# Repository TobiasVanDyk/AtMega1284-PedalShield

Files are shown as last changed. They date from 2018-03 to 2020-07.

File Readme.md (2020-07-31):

# The ATMega1284P Guitar and Music Effects Pedal 

Instructable at: https://www.instructables.com/id/ATMega1284P-Guitar-and-Music-Effects-Pedal/

I have ported the Arduino Uno ATMega328 Pedalshield (as developed by Electrosmash and in part based on work at the Open Music Lab) to the ATMega1284P which has eight times more RAM than the Uno (16kB versus 2kB). An additional unexpected benefit is that the Mega1284 build has much lower noise component - to the extent that when I compare the Uno and the Mega1284 using the same support circuitry it is not unreasonable to describe the Uno as "noisy" and the Mega1284 as "quiet". The larger RAM means that a much longer delay effect can be obtained - and that is demonstrated by the Arduino sketch example that I have included. The background breathing noise when using the Tremelo effect is also (almost) absent with the ATMega1284. 

A comparison of three Atmel AVR microprocessors namely the 328P that is the Uno, the 2560P that is the Mega2560, and the Mega1284 shows the latter to have the most RAM of the three: 

|Aspect | 328P | 1284P  | 2560P |
|---|---|---|---|
|RAM 	 |	2k 	 | 16k | 8k |
|Flash 	 |	32k  | 128k | 256k  |
|EEPROM |	1k	 | 4k 	  | 4k |
|UART 	 |	1 	 | 2 	 | 4 |
|IO Pins |	23 	 | 32 	  | 86 |
|Interrupts |	2 	 | 3 | 8 |
|Analog Inputs| 6	 | 8 	 | 16 |

I started by bread-boarding the Uno-based pedalSHIELD as in the Electrosmash specification but I did not have the same RRO OpAmp as specified. As a result I ended up with a circuit which I considered to give acceptable results. The details of this Uno version are given in appendix 2. This same circuit was then ported to the ATMega1284 - surprisingly apart from the non-essential changes such as assigning the switches and LED to a different port, and allocating 12,000 kB instead of 2,000 kB of RAM for the delay buffer, only **one essential change had to be made in the source code, namely changing the Timer1/PWM OC1A and OC1B outputs from Port B on the Uno to Port D (PD5 and PD4) on the ATMega1284.** 

I later discovered the excellent modifications to the electrosmash circuit by Paul Gallagher and after testing, this is the circuit I will present here - but then also with the substitution of the Uno with the Mega1284 and using a Texas Instruments TLC2272 as the OpAmp, and because of the excellent noise performance of the Mega1284 I could also raise the low-pass filter frequency level. It is important to note that although development boards for the ATMega1284 are available (Github: MCUdude MightyCore), it is an easy exercise to buy the bare (bootloader-free) chip (buy the PDIP version which is bread-board and strip-board friendly), then load the Mark Pendrith fork of the Maniacbug Mighty-1284p Core Optiboot bootloader or the MCUdude Mightycore, by using an Uno as the ISP programmer, and then loading sketches again via the Uno to the AtMega1284. Details and links for this process are given in appendix 1. 

I would like to acknowledge the three most important sources from which further information can be obtained and will give links to their websites and the end of this article: Electrosmash, Openlabs Music, and Tardate/Paul Gallagher Construction and Parts list: 

### Parts list: 

* ATMega1284P (PDIP 40 pin package version) Arduino Uno R3 (used as an ISP to transfer the bootloader and sketches to the ATMega1284) 
* OpAmp TLC2272 (or similar RRIO (Rail to Rail Input and Output) OpAmp such as MCP6002, LMC6482, TL972) 
* Red LED 16 MHz crystal 
* 2 x 27 pF capacitors 
* 5 x 6n8 capacitors 
* 270 pF capacitor 
* 4 x 100n capacitors 
* 2 x 10uF 16v electrolytic capacitors 
* 6 x 4k7 resistors 
* 100k resistor 
* 2 x 1M resistors 
* 470 ohm resistor 
* 1M2 resistor 
* 100k Potentiometer 
* 3 x pushbutton switches (one of them should be substituted with a 3-pole 2-way footswitch if the effects box is going to be used for live work) 

### Construction:

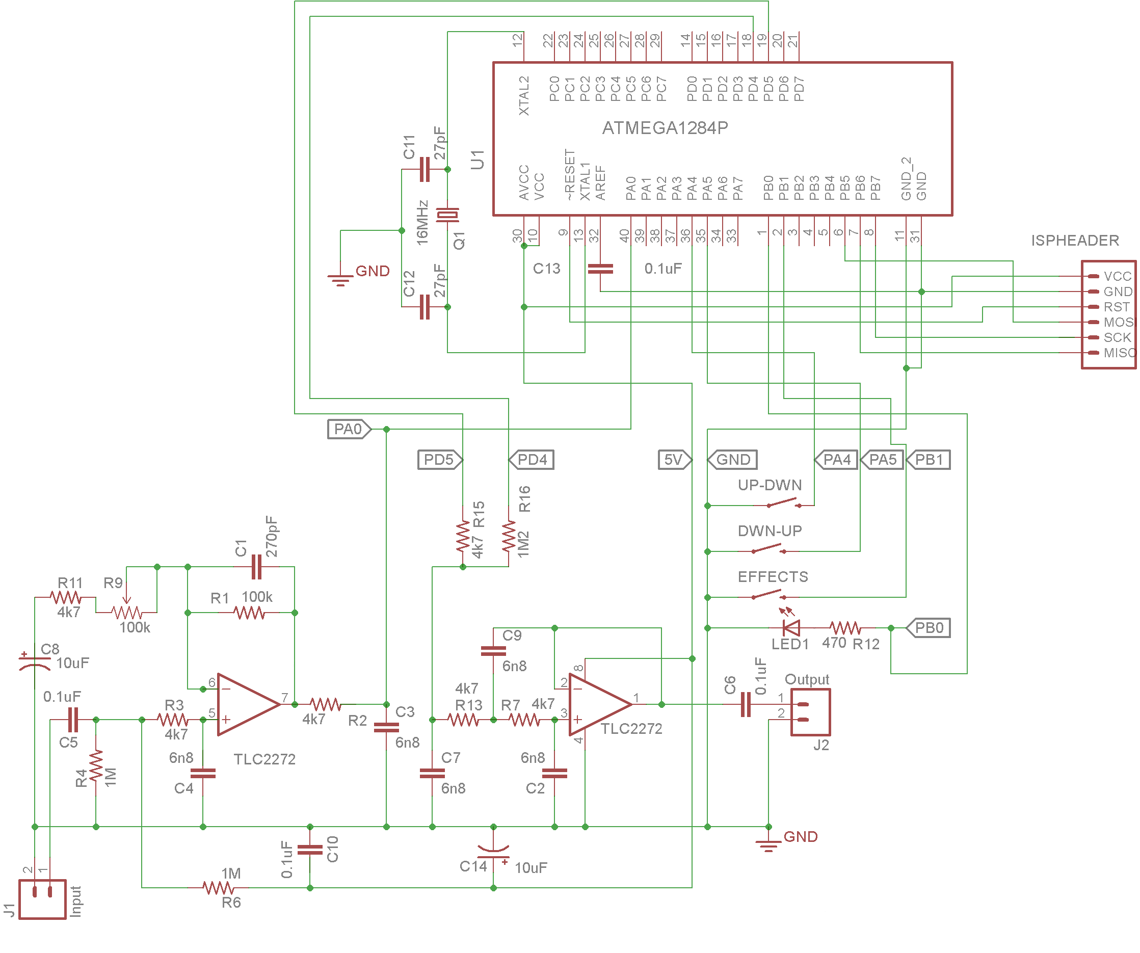
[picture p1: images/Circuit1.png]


Schematic 1 gives the circuit used and Breadboard 1 is its physical representation (Fritzing 1) with Photo 1 the actual bread-boarded circuit in operation. It may be advantageous to have a potentiometer as a mixer for the dry (equal to the input) and the wet (after processing by the MCU) signal, and Schematic 2, Breadboard 2 and Photo 2 gives the circuit details of a previously constructed circuit which incorporates such an input to output mixer. Also look at the Open Music Labs StompBox for another mixer implementation using four OpAmps. 

**OpAmp Input and Output Stages:** It is important that a RRO or preferably a RRIO OpAmp is used because of the large voltage swing required at the OpAmp output to the ADC of the ATMega1284. The parts list contains a number of alternative OpAmp types. The 100k potentiometer is used to adjust the input gain to a level just below any distortion, and it can also be used to adjust the input sensitivity for an input source other than a guitar such as a music player. The OpAmp output stage has a higher order RC filter to remove the digitally generated MCU noise from the audio stream. 

**ADC Stage:** The ADC is configured to be reading via an interrupt all the whole time. Note that a 100nF capacitor should be connected between the AREF pin of the ATMega1284 and ground to reduce noise as an internal Vcc source is used as a reference voltage - do NOT connect the AREF pin to +5 volt directly! 

**DAC PWM Stage:** As the ATMega1284 does not have its own DAC, the output audio waveforms are generated using a pulse width modulation of an RC filter. The two PWM outputs on PD4 and PD5 are set as the high and low bytes of the audio output and mixed with the two resistors (4k7 and 1M2) in a 1:256 ratio (low byte and high byte) - which generates the audio output. It may be worthwhile experimenting with other resistor pairs such as the 3k9 1M ohm pair used by Open Music Labs in their StompBox. 

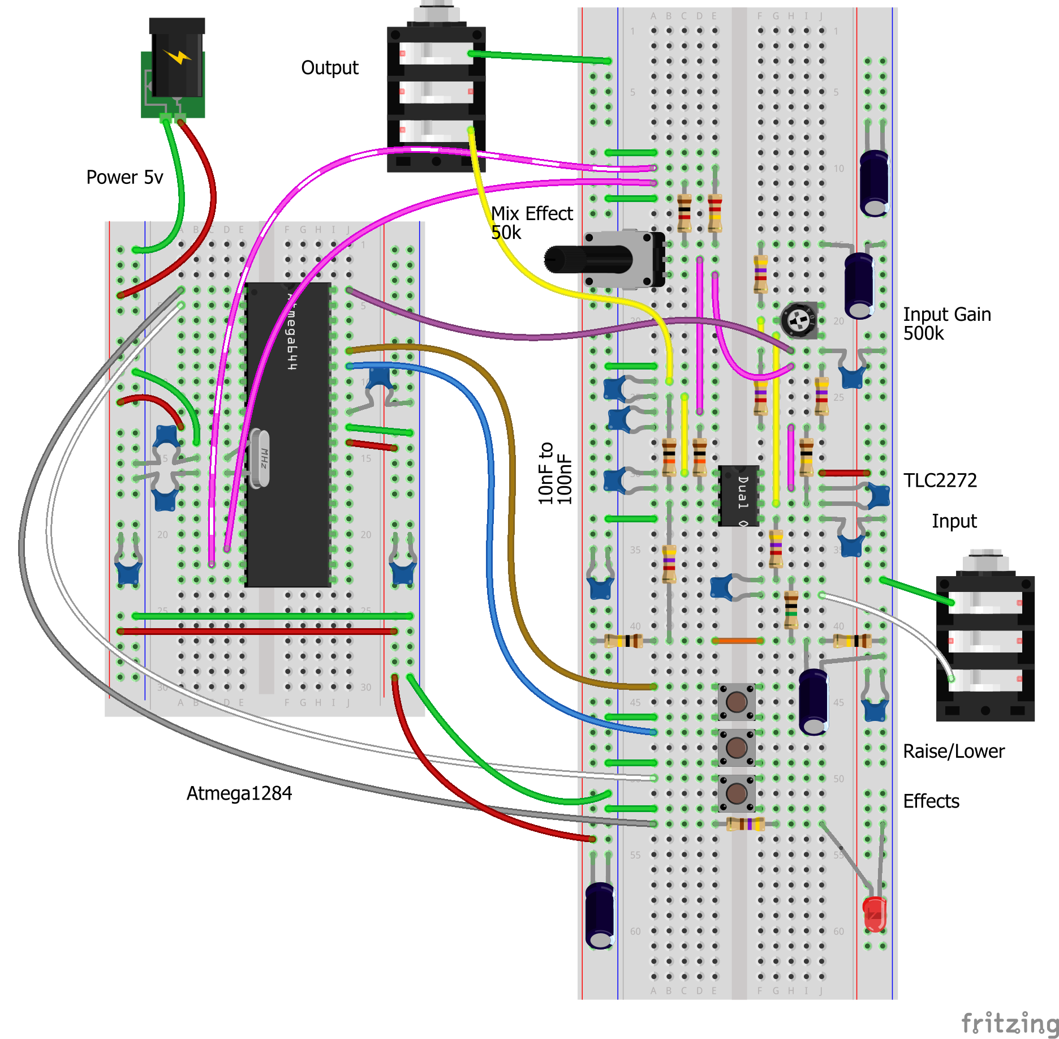
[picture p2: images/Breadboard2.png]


### Software: 

The software is based on the electrosmash sketches, and the example included (pedalshield1284delay.ino), has been adapted from their Uno delay sketch. Some of the switches and LED had been moved to other ports away from those used by the ISP programmer (SCLK, MISO, MOSI and Reset), the delay buffer has been increased from 2000 bytes to 12000 bytes, and PortD has been set as the output for the two PWM signals. Even with the increase in the delay buffer the sketch still use only about 70% of the available 1284 RAM. 

Other examples such as the octaver or tremolo from the electrosmash website for the pedalSHIELD Uno can be adapted for use by the Mega1284 by changing three sections in the code: 

(1) Change:
```
DDRB |= ((PWM_QTY << 1) | 0x02); 
to 
DDRD |= 0x30;
// The change above is the ONLY essential code change 
// when porting from the AtMega328 to the ATMega1284 
```

(2) Change:
``` 
#define LED 13 
#define FOOTSWITCH 12 
#define TOGGLE 2 
#define PUSHBUTTON_1 A5 
#define PUSHBUTTON_2 A4
to
#define LED PB0 
#define FOOTSWITCH PB1 
#define PUSHBUTTON_1 A5 
#define PUSHBUTTON_2 A4
```

(3) Change:
```
pinMode(FOOTSWITCH, INPUT_PULLUP); 
pinMode(TOGGLE, INPUT_PULLUP); 
pinMode(PUSHBUTTON_1, INPUT_PULLUP); 
pinMode(PUSHBUTTON_2, INPUT_PULLUP); 
pinMode(LED, OUTPUT)
to
pinMode(FOOTSWITCH, INPUT_PULLUP); 
pinMode(PUSHBUTTON_1, INPUT_PULLUP); 
pinMode(PUSHBUTTON_2, INPUT_PULLUP); 
pinMode(LED, OUTPUT);
```

The pushbuttons 1 and 2 are used in some of the sketches to increase or decrease an effect. In the delay example it increases or decreases the delay time. When the sketch is first loaded it starts with the maximum delay effect. press the down button - it takes about 20 seconds to count down all the way to the delay-off position - and then press and hold in the up button. Listen how the sweep effect of holding in the button changes the effect to that of a phaser, chorus and flanging, as well as the delay when the button is released.

To change the delay to an echo effect (add repetition) change the line:
```
DelayBuffer[DelayCounter] = ADC_high; 
to
DelayBuffer[DelayCounter] = (ADC_high + (DelayBuffer[DelayCounter]))>>1; 
```

The footswitch should be a three pole two way switch and must be connected as described on the electrosmash website. 

### Links: 
1. Electrosmash: https://www.electrosmash.com/pedalshield-uno 
License: https://creativecommons.org/licenses/by-nc/3.0/ 
2. Openlabs Music: http://wiki.openmusiclabs.com/wiki/StompShield License: http://www.openmusiclabs.com/ 
3. Paul Gallagher: https://github.com/tardate/LittleArduinoProjects/tree/master/playground/AudioDSP 
License: https://github.com/tardate/LittleArduinoProjects/blob/master/LICENSE (MIT) 
4. 1284 Bootloader: https://github.com/JChristensen/mighty-1284p https://github.com/maniacbug/mighty-1284p 
5. ATmega1284 8bit AVR Microcontroller: https://www.microchip.com/wwwproducts/en/ATmega1284 

### Appendix 1 

**Programming the ATMega1284P:** There are a few websites that gives a good explanation on how to program the bare ATMega1284 chip for use with the Arduino IDE. 

The process is essentially as follows: 
* (1) Install the Mark Pendrith fork of the Maniacbug Mighty-1284p Core Optiboot bootloader into the Arduino IDE. 
* (2) Wire up the ATMega1284 on a breadboard with its minimum configuration that is a 16 MHz crystal, 2 x 22 pF capacitors that grounds the two end of the crystal, Connect the two ground pins together (pins 11 and 31), and then to the Arduino Uno ground, connect the Vcc and AVcc together (pins 10 and 30), and then to the Uno +5v, then connect the reset pin 9 to the Uno D10 pin, the MISO pin 7 to the UNO D12, The MOSI pin 8 to the Uno D11, and the SCLK pin 7 to the Uno D13 pin. 
* (3) Connect the Uno to the Arduino IDE and load the sketch example Arduino as ISP onto the Uno. 
* (4) Now select the 1284 "maniac" mighty optiboot board, and choose the Burn bootloader option. 
* (5) Then select the 1284 delay sketch given here as an example and upload it by using use the Uno as programmer option in the sketches menu. 

**Links that explain the process in more detail are:**
* Using the ATmega1284 with the Arduino IDE http://www.technoblogy.com/show?19OV
* Arduino Mightycore for large breadboard friendly AVRs https://github.com/MCUdude/MightyCore
* Building an ATMega1284p prototype https://dave.cheney.net/2014/12/31/building-an-atmega1284p-prototype
* Arduino ATmega1284p bootloader https://forum.arduino.cc/index.php?topic=137559.0

### Appendix 2 

Arduino Uno pedalSHIELD variation Schematic3, Breadboard3, and Photo3 gives details of the Uno-based circuit that preceded the AtMega1284 build.

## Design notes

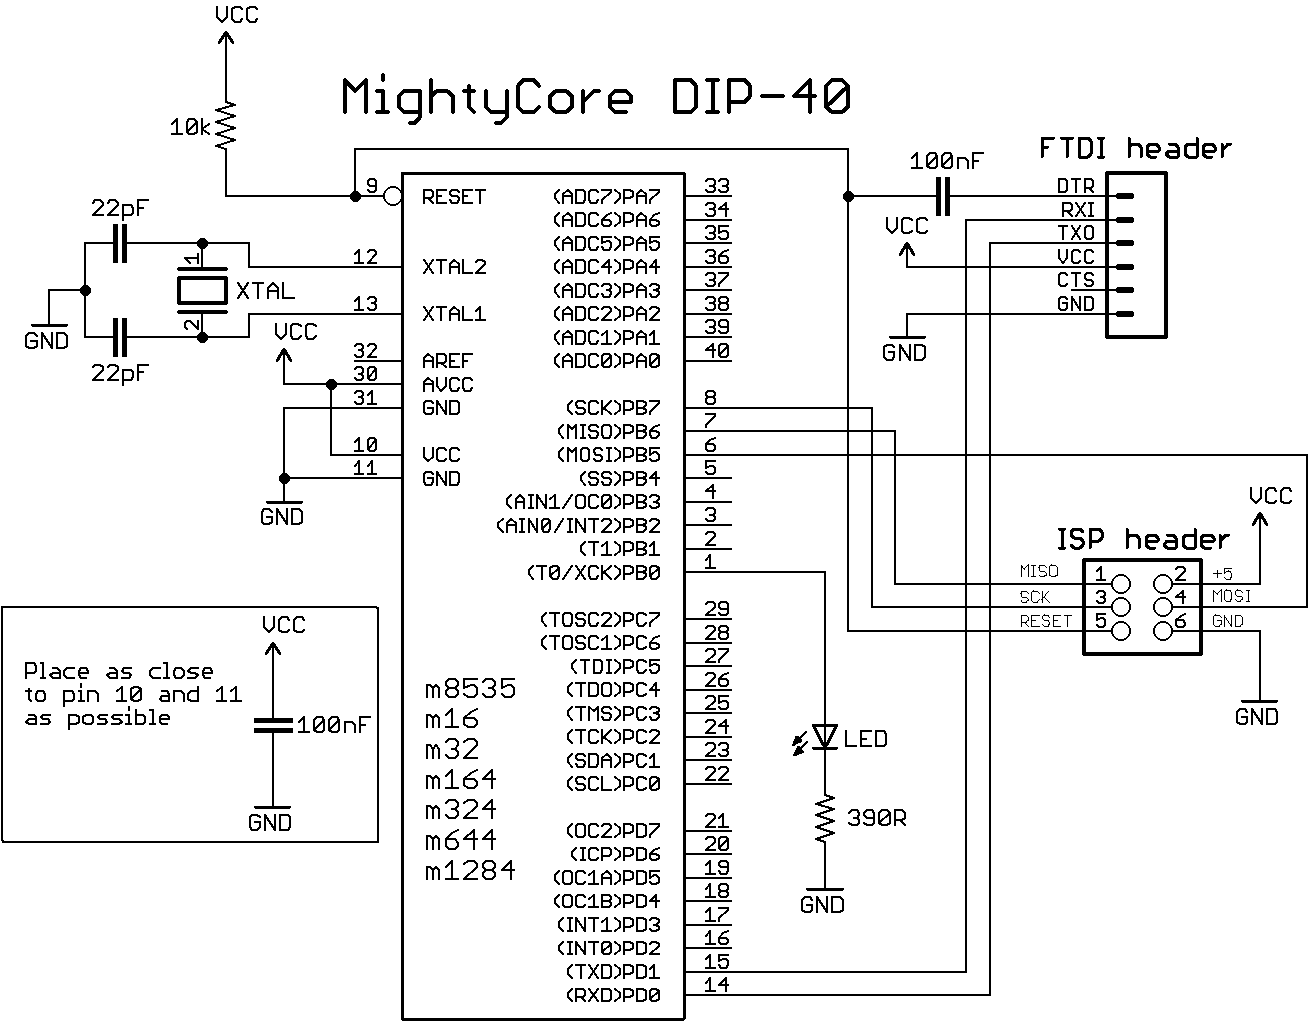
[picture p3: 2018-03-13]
images/MinimumSchematic.png

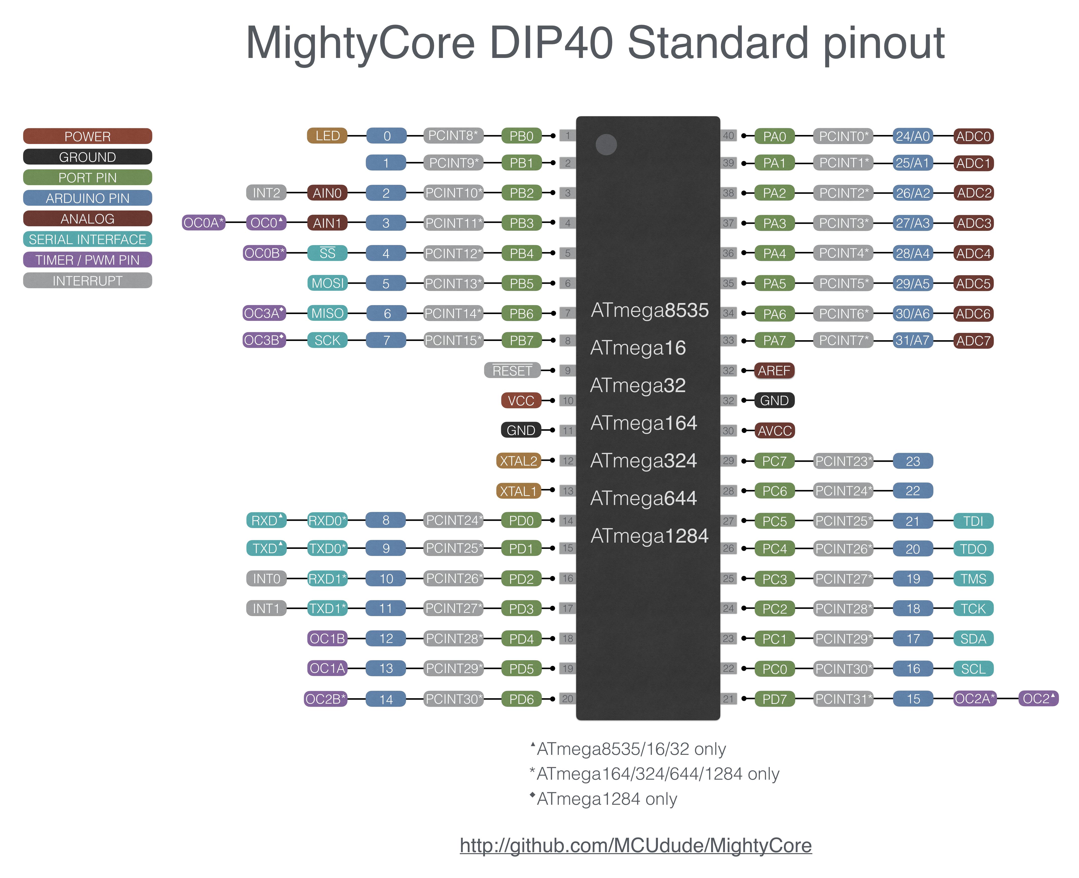
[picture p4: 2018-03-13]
images/DetailedPinout.jpg

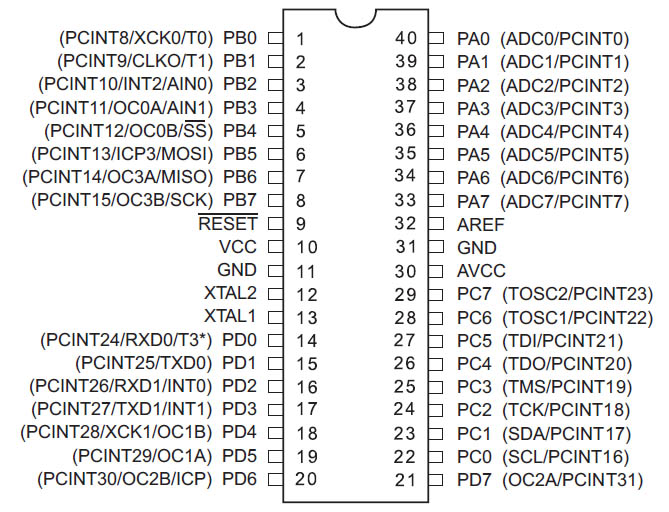
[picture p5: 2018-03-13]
images/ATMega1284PDIP.jpg

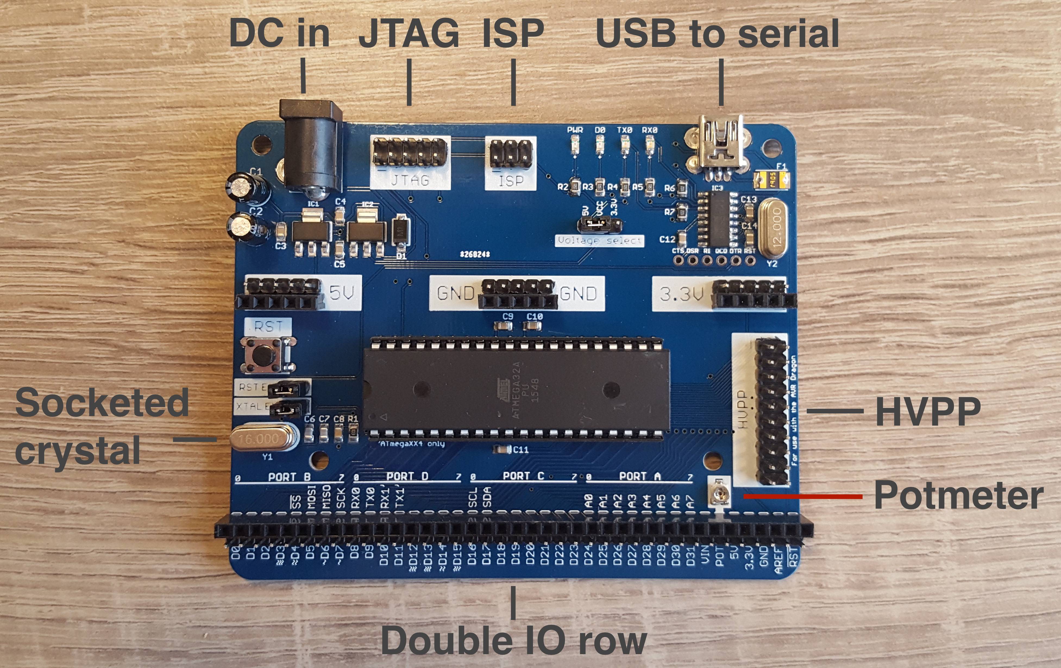
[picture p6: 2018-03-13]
images/DevelopmentBoard.jpg

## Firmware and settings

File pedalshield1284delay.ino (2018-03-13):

/////////////////////////////////////////////////////////////////////////////////////////////
// CC-by-www.Electrosmash.com based on OpenMusicLabs previous works
// 
// pedalshield1284delay.ino reads the ADC, 
// saves it into the DelayBuffer array and plays it into the PWM output
//  
// Pressing the pushbutton_1 or 2 makes the delay longer or shorter
// Pressing the footswitch disables the effect
// 
// Compared to the Uno R3 with the same support circuit the ATMega1284 sounds very quiet
// This is also true for the Tremelo breathing noise that was very noticable on te Uno
// Much longer delays now possible with the 16k RAM
//
// Code and accompying schematics adapted by Tobias van Dyk January 2018
// 
/////////////////////////////////////////////////////////////////////////////////////////////

// defining harware resources.
#define LED PB0
#define FOOTSWITCH PB1
#define PUSHBUTTON_1 A5
#define PUSHBUTTON_2 A4

// defining the output PWM parameters
#define PWM_FREQ 0x00FF             // pwm frequency - 31.3KHz
#define PWM_MODE 0                  // Fast (1) or Phase Correct (0)
#define PWM_QTY 2                   // 2 PWMs in parallel

// other variables
int input, vol_variable=512;
int counter=0;
unsigned int ADC_low, ADC_high;

#define MAX_DELAY 12000        // With this only 72% of ATMega1284 RAM used
byte DelayBuffer[MAX_DELAY];
byte EffectEnable = 1;
unsigned int DelayCounter = 0;
unsigned int Delay_Depth = MAX_DELAY;

void setup() {
  //setup IO
  pinMode(FOOTSWITCH, INPUT_PULLUP);
  pinMode(PUSHBUTTON_1, INPUT_PULLUP);
  pinMode(PUSHBUTTON_2, INPUT_PULLUP);
  pinMode(LED, OUTPUT);
  
  // setup ADC
  ADMUX = 0x60;   // left adjust, adc0, internal vcc
  ADCSRA = 0xe5;  // turn on adc, ck/32, auto trigger
  ADCSRB = 0x07;  // t1 capture for trigger
  DIDR0 = 0x01;   // turn off digital inputs for adc0

  // setup PWM
  TCCR1A = (((PWM_QTY - 1) << 5) | 0x80 | (PWM_MODE << 1)); //
  TCCR1B = ((PWM_MODE << 3) | 0x11);                        // ck/1
  TIMSK1 = 0x20;                                            // interrupt on capture interrupt
  ICR1H = (PWM_FREQ >> 8);
  ICR1L = (PWM_FREQ & 0xff);
  DDRD |= 0x30;                                             // turn on PWM outputs PD4 and PD5
  sei();                                                    // turn on interrupts  
  }

/*

  // setup ADC to sample on ADC2
  ADMUX = 0x62; // left adjust, adc2, internal vcc as reference
  ADCSRA = 0xe5; // turn on adc, ck/32, auto trigger
  ADCSRB =0x06; // timer1 overflow as trigger
  DIDR0 = 0x04; // turn off digital inputs for adc2

  // setup PWM to output at 31.25ksps
  TCCR1A = 0xa0; // set to compare mode to positive output
  TCCR1B = 0x11; // ck/1, phase and frequency correct mode, ICR1 as top
  TIMSK1 = 0x01; // turn on overflow interrupt
  ICR1H = 0x00; // clear temporary high byte register
  ICR1L = 0xff; // set top of counter
  DDRB |= 0x06; // set pwm outputs (pins 9,10) to output

}


*/



void loop() 
{
  // Turn on the LED if the effect is ON.
  if (digitalRead(FOOTSWITCH)) {digitalWrite(LED, HIGH); 
                                EffectEnable = 1;
                               } else  
                               {digitalWrite(LED, LOW);
                                EffectEnable = 0; }
                                
  // Everthing happens in the Timer 1 interruption
  
}

ISR(TIMER1_CAPT_vect) 
{
  // get ADC data
  ADC_low = 0; // ADC_low always 0 to save space
  ADC_high = ADCH;
  
  //store the high bit only for 
  DelayBuffer[DelayCounter] = ADC_high;
 
counter++; //to save resources, the pushbuttons are checked every 100 times.
if(counter==100)
{ 
counter=0;
if (!digitalRead(PUSHBUTTON_1)) {
  if (Delay_Depth<MAX_DELAY)Delay_Depth=Delay_Depth+1; //increase the depth
    digitalWrite(LED, LOW);   // unblinks the led
    }

    if (!digitalRead(PUSHBUTTON_2)) {
  if (Delay_Depth>0)Delay_Depth=Delay_Depth-1; //decrease depth
  digitalWrite(LED, LOW);     // unblinks the led
    }
}

//Increase/reset delay counter.   
  DelayCounter++;
  if(DelayCounter >= Delay_Depth) DelayCounter = 0; 

  input = (((DelayBuffer[DelayCounter] << 8) | ADC_low) + 0x8000)+(((ADC_high << 8) | ADC_low) + 0x8000); // make a signed 16b value
  
  //write the PWM signal
  if (EffectEnable==1)
  {
  OCR1AL = ((input + 0x8000) >> 8);       // convert to unsigned, send out high byte
  OCR1BL = input; // send out low byte    // PortD for the ATMega1284
  }

}
